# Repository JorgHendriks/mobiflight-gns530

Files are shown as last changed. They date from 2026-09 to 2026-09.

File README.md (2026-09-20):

# GNS 530 Flight-Simulator GPS

A DIY Garmin GNS 530-inspired panel for flight simulation, designed for use with [MobiFlight](https://www.mobiflight.com/). The project includes a Raspberry Pi Pico, custom PCB, a 5-inch LCD, a printed and laser-engraved enclosure, Mobiflight configuration.

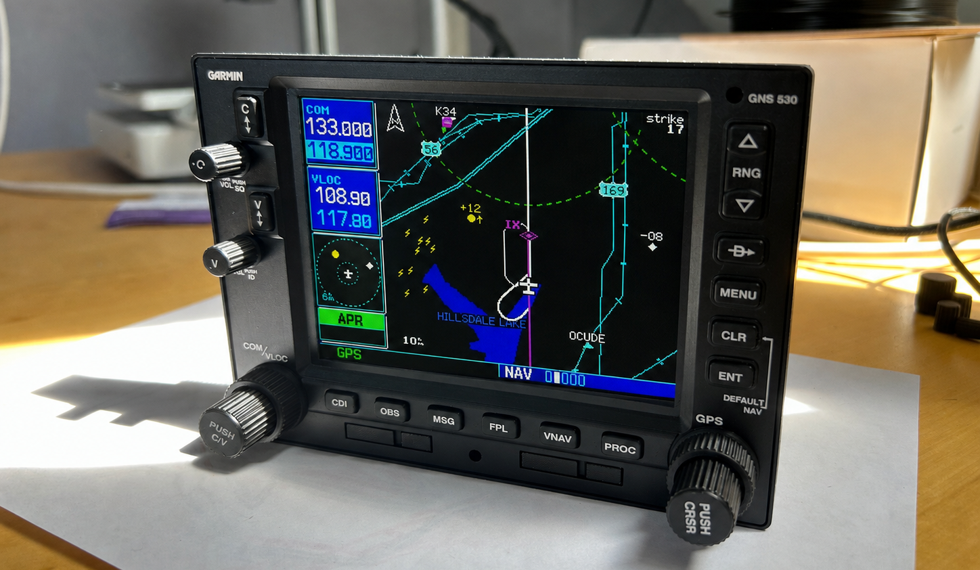
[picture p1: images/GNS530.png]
Completed GNS 530 flight-simulator panel


> [!IMPORTANT]
> This is an unofficial hobby project for flight simulation. It is not certified
> for aviation use and is not affiliated with or endorsed by Garmin.

## Features

- COM/VLOC and GPS dual-concentric encoders
- Illuminated GNS 530 controls
- 5-inch 640 x 480 display with HDMI, VGA, and composite-video input
- Adjustable panel illumination
- Editable KiCad and FreeCAD sources
- Printable parts, laser artwork, schematic, BOM, and PCB fabrication files

## Repository contents

| Folder | Contents |
|---|---|
| [`pcb`](pcb) | KiCad source, schematic, BOM, fabrication archive, display references, and assembly notes |
| [`mechanical`](mechanical) | FreeCAD source, printable parts, hardware, painting, and laser settings |
| [`mobiflight`](mobiflight) | Pico module configuration and Microsoft Flight Simulator project |

## What you need

- The components in the [PCB bill of materials](pcb/README.md#bill-of-materials)
- The printed parts and GNS530-specific [mounting hardware](mechanical/README.md#hardware)
- PCB800099 video controller and ZJ050NA-08C 5-inch LCD
- 12 V DC power supply rated above 1 A for the video controller
- Raspberry Pi Pico, MobiFlight

## Build documentation

1. Manufacture and assemble the board using the [PCB guide](pcb).
2. Print, paint, engrave, and assemble the enclosure using the
   [mechanical guide](mechanical).
3. Use the official MobiFlight documentation for
   [board configurations](https://docs.mobiflight.com/features/file-types/),
   [projects](https://docs.mobiflight.com/features/projects/), and
   [controller bindings](https://docs.mobiflight.com/features/controller-bindings/).

The supplied MobiFlight files are [`GNS530.mfmc`](mobiflight/GNS530.mfmc) and
[`GNS530.mfproj`](mobiflight/GNS530.mfproj).

## Licence

Original project material is licensed under
[CC BY-NC-SA 4.0](https://creativecommons.org/licenses/by-nc-sa/4.0/).
Third-party material and trademarks remain the property of their owners.

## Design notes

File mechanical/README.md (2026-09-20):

# Enclosure and controls

## Hardware

| Part | Quantity |
|---|---:|
| M2 x 8 mm screw | 5 |
| M2 x 4 mm screw | 4 |
| M2 x 9 mm, 3 mm body standoff | 5 |
| M2 x 4 mm, 3 mm body standoff | 4 |
| M2 x 11 mm, 3 mm body standoff | 4 |

## Printed parts

| File | Quantity | Material |
|---|---:|---|
| [`GNS530_case.3mf`](GNS530_case.3mf) | 1 | Matte-black PLA |
| [`GNS530_back_cover.3mf`](GNS530_back_cover.3mf) | 1 | Matte-black PLA |
| [`GNS530_faceplate.3mf`](GNS530_faceplate.3mf) | 1 | White PLA, painted matte black |
| [`GNS530_button.3mf`](GNS530_button.3mf) | 12 plus spares | White PLA, painted matte black |
| [`GNS530_button_rng.3mf`](GNS530_button_rng.3mf) | 1 plus a spare | White PLA, painted matte black |
| [`GNS530_knob_inner.3mf`](GNS530_knob_inner.3mf) | 2 | Black PLA |
| [`GNS530_knob_outer.3mf`](GNS530_knob_outer.3mf) | 2 | White PLA, painted matte black |
| [`GNS530_knob_volume.3mf`](GNS530_knob_volume.3mf) | 2 | White PLA, painted matte black |

The complete editable model is [`GNS530.FCStd`](GNS530.FCStd). Editable knob
sources are [`GNS530_encoder_dual.FCStd`](GNS530_encoder_dual.FCStd) and
[`GNS530_encoder_volume.FCStd`](GNS530_encoder_volume.FCStd).

## Printing

Print several spare knobs and buttons. They require little filament or paint, and achieving correct laser alignment may take more than one attempt.
Print inner knobs with their top surfaces facing down on a smooth PEI plate.

| Button setting | Value |
|---|---|
| Wall generator | Arachne |
| Initial-layer flow ratio | 1.06 |
| Bottom-surface pattern | Hilbert curve |
| Elephant-foot compensation | 0.08 mm |

Print the buttons and the faceplate with its visible face upward and enable ironing at 23% flow.

## Painting and laser engraving

Apply thin coats of matte-black paint to the white PLA parts. Let the paint cure fully before engraving.

The artwork is [`GNS530_laser.svg`](GNS530_laser.svg).

Reference settings for a Mecpow X3 Pro 10 W diode laser:

| Operation | Power | Speed |
|---|---:|---:|
| Faceplate and button raster | 15% | 2800 mm/min |
| Positioning outline | 50% | 2000 mm/min |

Run separate sessions for the faceplate, knobs, standard buttons, and range rocker.
Focus on the part surface, remove the part, engrave its positioning outline onto a sacrificial surface, then replace the part inside the outline and run the raster engraving.

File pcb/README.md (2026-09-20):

# PCB

## PCB manufacturing

The ready-to-order fabrication archive is
[`GNS530_v1_1_pcb_fab.zip`](GNS530_v1_1_pcb_fab.zip). Use a standard board
thickness of **1.6 mm**.

- [KiCad project](GNS530.kicad_pro)
- [Schematic PDF](GNS530_schematic.pdf)

The local symbol and footprint libraries are referenced through `${KIPRJMOD}`.

## Bill of materials

| Designators | Qty | Component | Specification |
|---|---:|---|---|
| RE_GPS1, RE_COM_VLOC1 | 2 | Dual-concentric encoder | PEC11D-4120F-S0015 |
| Q2 | 1 | P-channel MOSFET | AO3401A, SOT-23 |
| C1 | 1 | Capacitor | 0.1 uF, 1206 |
| R1-R23, R32-R36 | 28 | Resistor | 220 ohm, 1206 |
| R24-R31, R39, R40 | 10 | Resistor | 10 kohm, 1206 |
| Q1 | 1 | NPN transistor | BC847, SOT-23 |
| SW_CDI1, SW_CLR1, SW_COM1, SW_DCT1, SW_ENT1, SW_FPL1, SW_MENU1, SW_MSG1, SW_OBS1, SW_PROC1, SW_RNG_D1, SW_RNG_UP1, SW_V1, SW_VNAV1 | 14 | Illuminated tactile switch | 6 x 6 x 7.2 mm, six pins |
| D1-D14 | 14 | LED | 3 mm clear through-hole |
| U1 | 1 | Shift register | 74HC165, SOIC-16 |
| RE_VOL_COM1, RE_VOL_V1 | 2 | Rotary encoder with switch | PEC11L-4220F-S0015 |
| EXT_LED1 | 1 | Two-pin header | 2.54 mm pitch |
| A1 | 1 | Microcontroller | Raspberry Pi Pico |
| - | 2 | Male pin header | 20 pins, 2.54 mm pitch |
| - | 2 | Female socket header | 20 pins, 2.54 mm pitch |

## Illuminated switches

Use 6 x 6 x 7.2 mm, six-pin illuminated tactile switches. Four pins form the
duplicated switch contacts; the remaining two connect the LED.

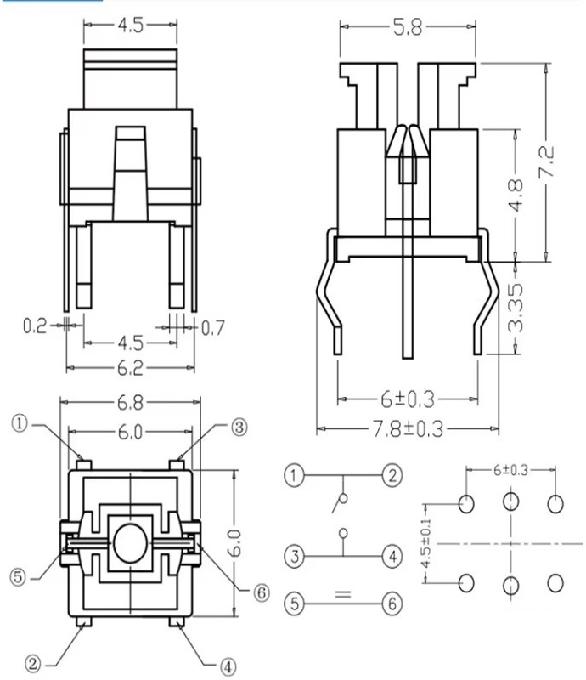
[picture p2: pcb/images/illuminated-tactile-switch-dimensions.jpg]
Illuminated tactile switch dimensions


The small square PCB pad is ground and connects to the negative LED terminal.

## Display

The enclosure is designed for a **PCB800099** HDMI/VGA/AV controller and
**ZJ050NA-08C** 5-inch 640 x 480 LCD.

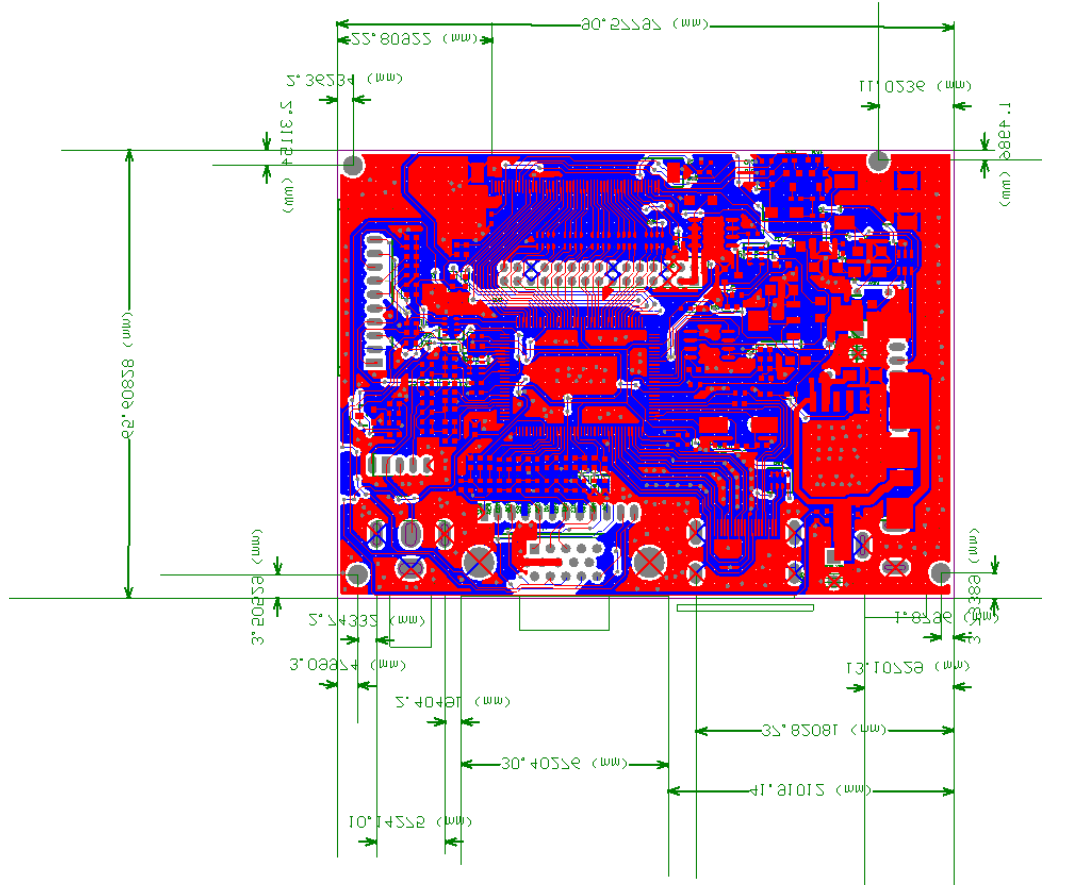
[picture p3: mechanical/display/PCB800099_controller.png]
PCB800099 controller


| Part | Specification |
|---|---|
| PCB800099 controller | 100 x 55 x 10 mm; 12 V DC, more than 1 A |
| ZJ050NA-08C LCD | 117.65 x 88.43 x 5.9 mm; 50-pin parallel RGB |

- [Controller dimensions](../mechanical/display/PCB800099_dimensions.png)
- [Controller datasheet](../mechanical/display/PCB800099_datasheet.pdf)
- [LCD datasheet](../mechanical/display/ZJ050NA-08C_datasheet.pdf)
- [Controller product image](../mechanical/display/PCB800099_product.jpg)

The display controller uses its own 12 V supply. Do not connect 12 V to the Pico or the LCD panel input.

If your controller board includes VGA and composite-video connectors, desolder
them before assembly. Alternatively, modify the back cover to provide adequate
clearance for the connectors.

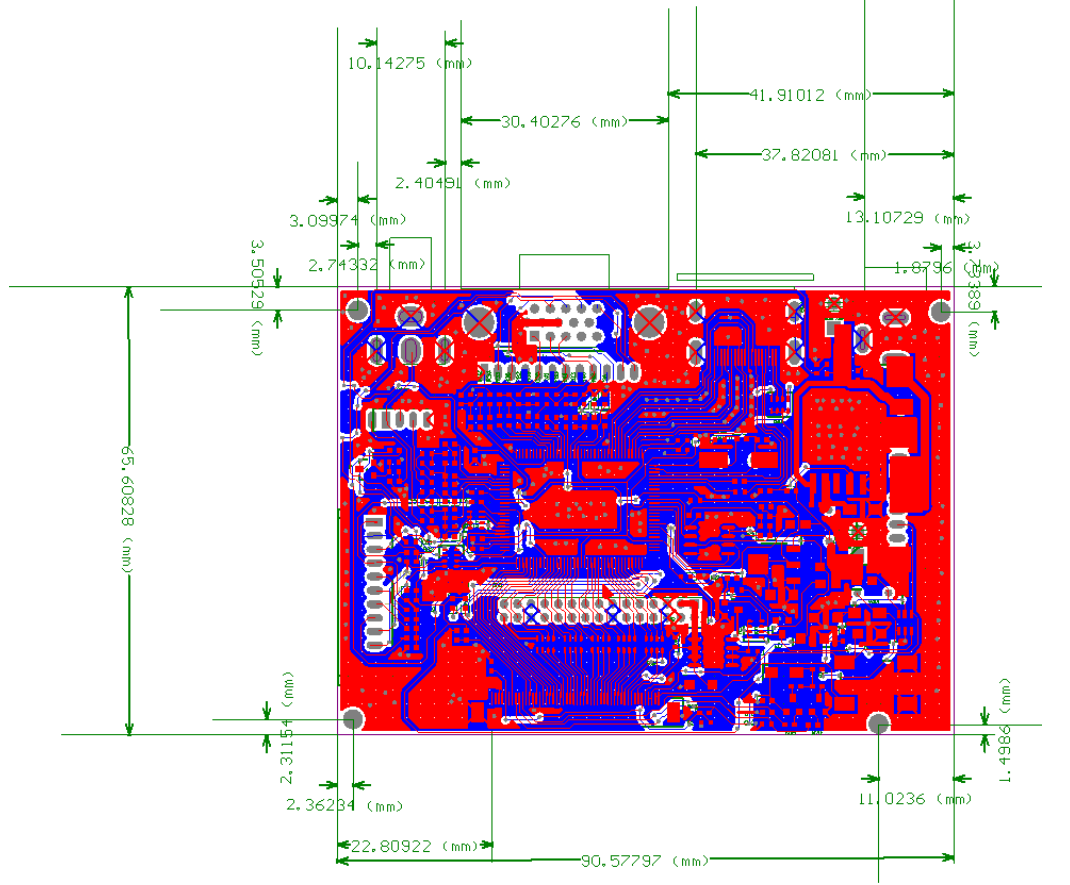
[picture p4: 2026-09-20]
mechanical/display/PCB800099_dimensions.png

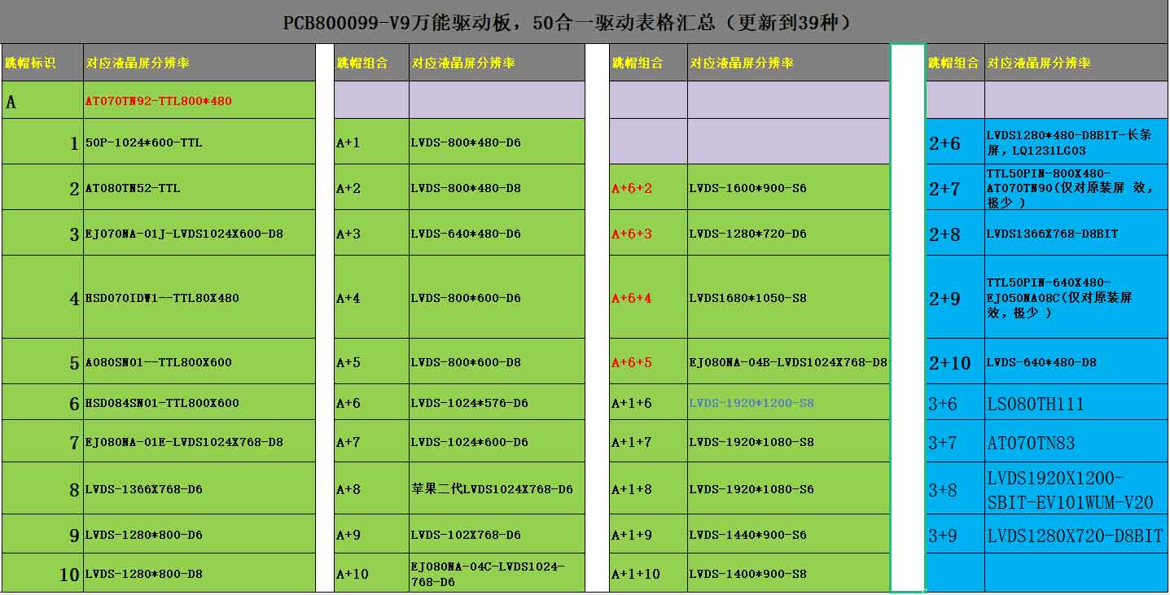
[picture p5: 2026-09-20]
mechanical/display/PCB800099_product.jpg

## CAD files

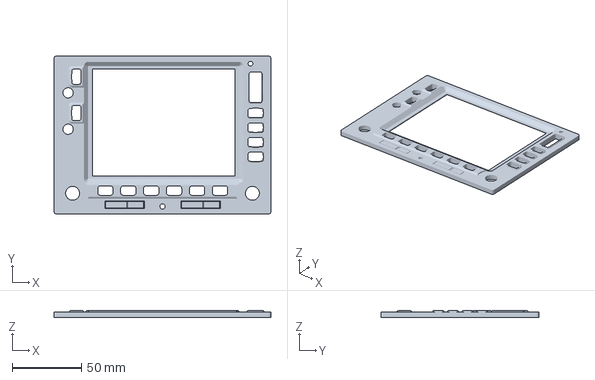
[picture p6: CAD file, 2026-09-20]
mechanical/GNS530_faceplate.3mf
156.3 x 113.9 x 5.00 mm

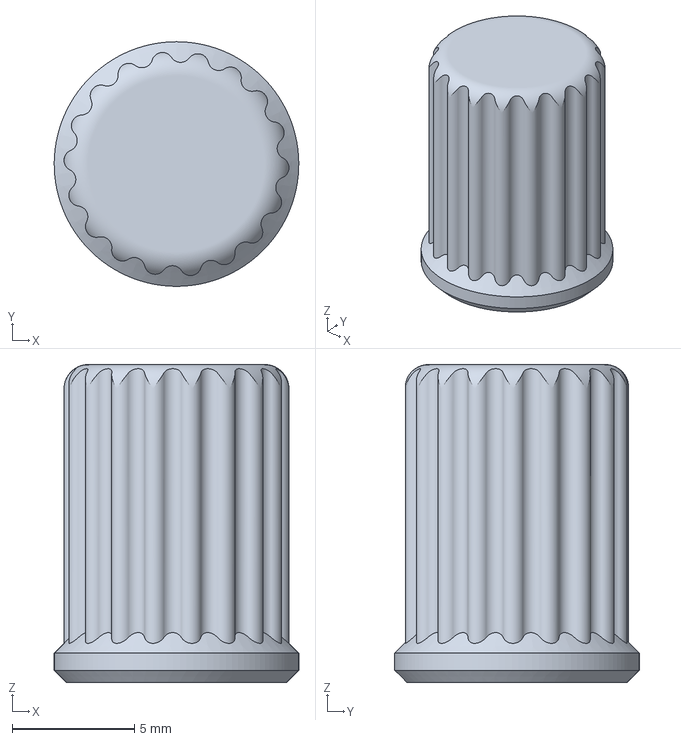
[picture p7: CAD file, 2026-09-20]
mechanical/GNS530_knob_volume.3mf
10.00 x 10.00 x 13.0 mm

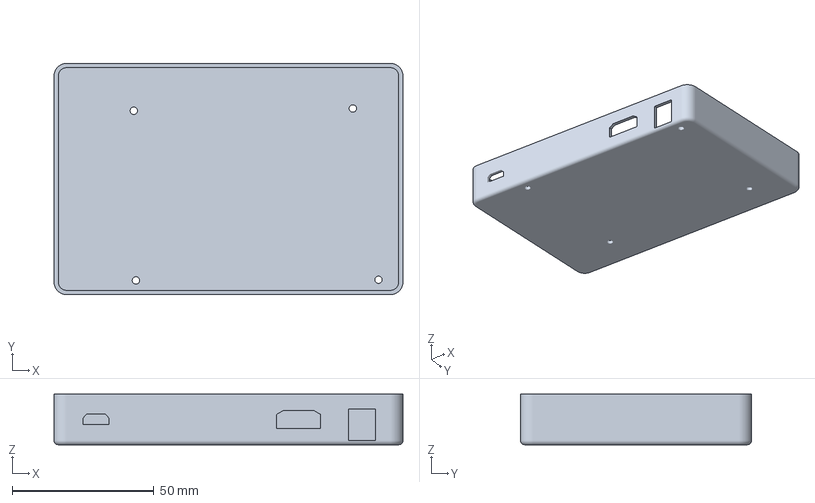
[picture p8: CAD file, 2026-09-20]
mechanical/GNS530_back_cover.3mf
123.0 x 81.5 x 17.8 mm

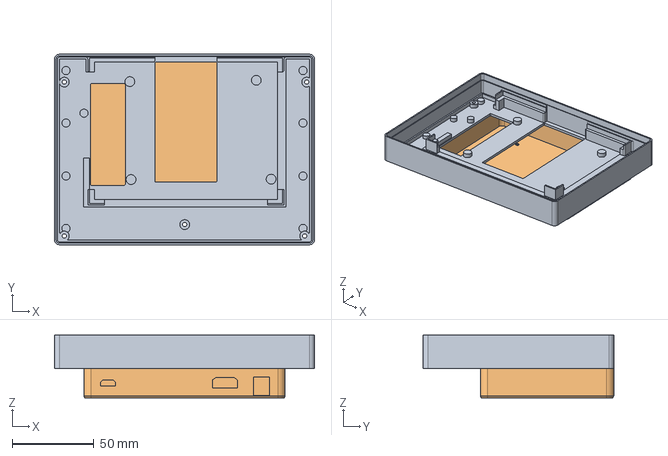
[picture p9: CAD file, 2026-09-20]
mechanical/GNS530.FCStd
158.8 x 116.3 x 38.2 mm
Case
hdmi_cover

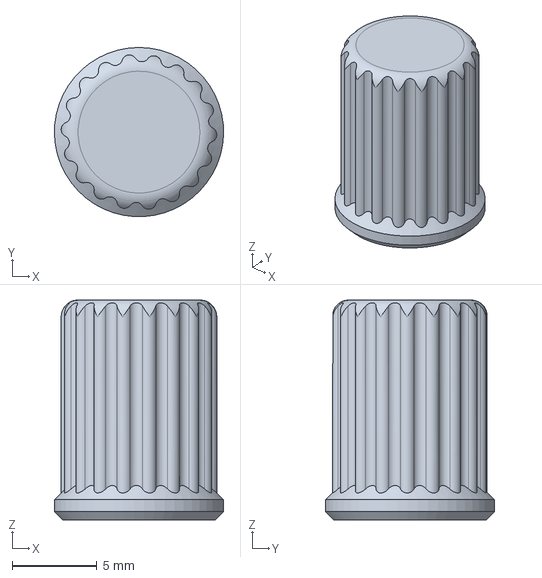
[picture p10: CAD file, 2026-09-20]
mechanical/GNS530_encoder_volume.FCStd
10.00 x 9.99 x 13.0 mm

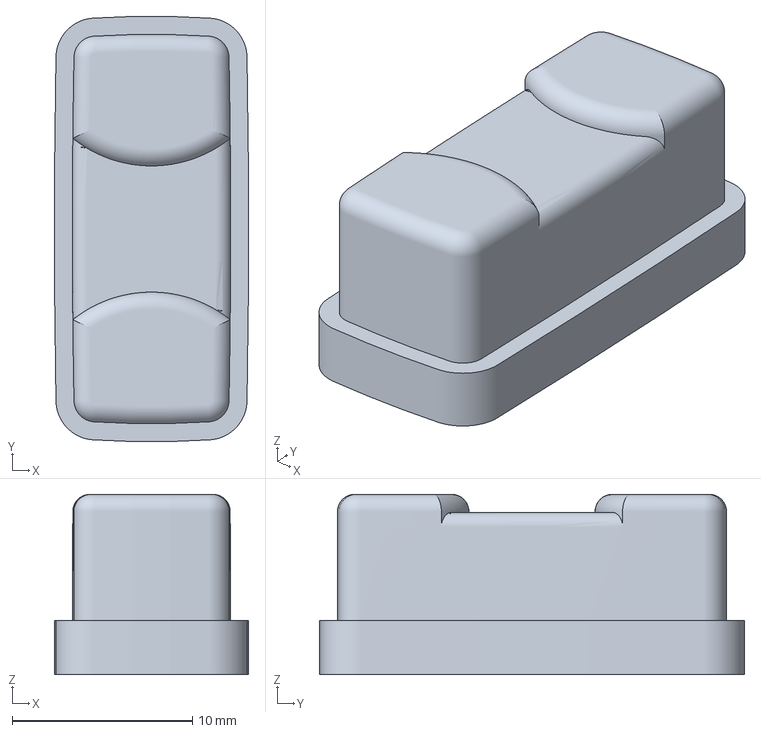
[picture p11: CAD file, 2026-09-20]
mechanical/GNS530_button_rng.3mf
10.8 x 23.6 x 10.0 mm

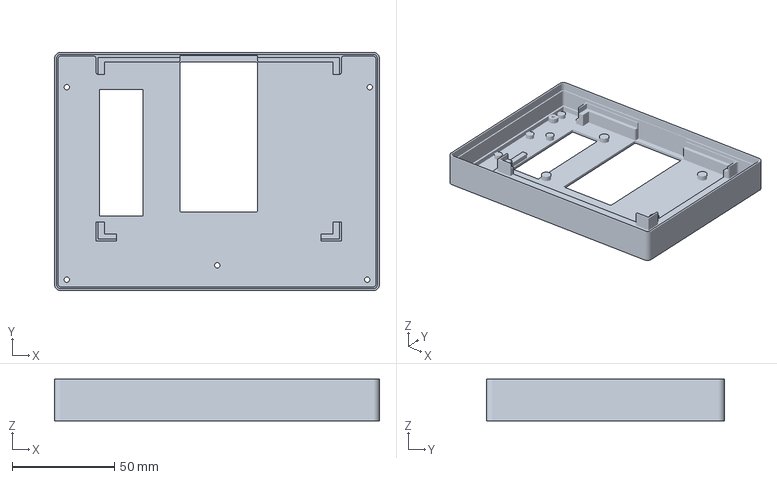
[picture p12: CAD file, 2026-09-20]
mechanical/GNS530_case.3mf
158.8 x 116.3 x 20.4 mm

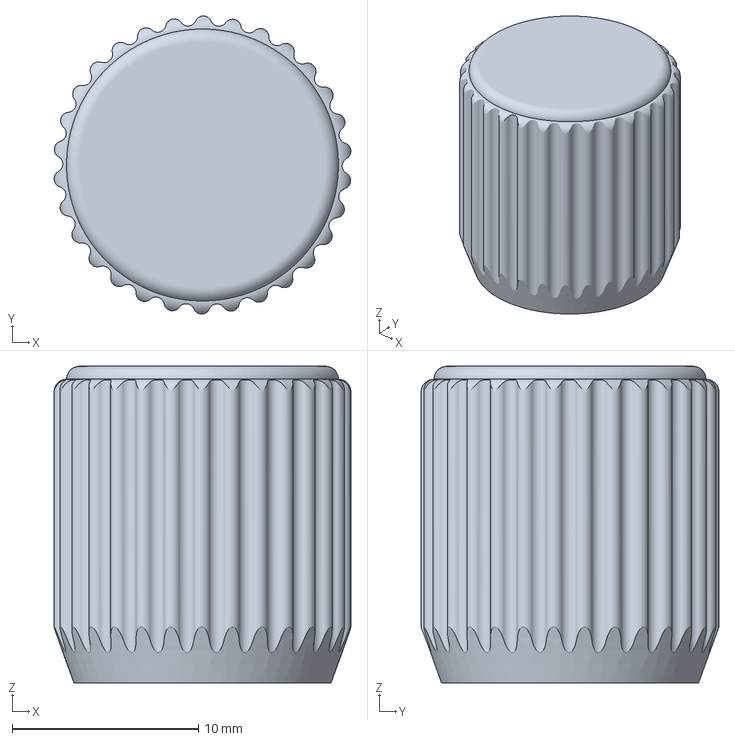
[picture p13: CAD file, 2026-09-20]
mechanical/GNS530_knob_inner.3mf
15.9 x 16.0 x 17.0 mm

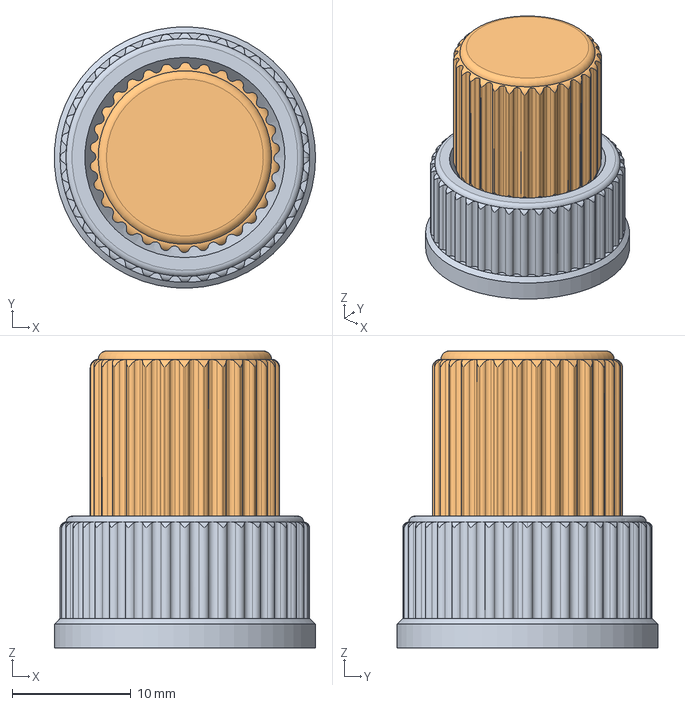
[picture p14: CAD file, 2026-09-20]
mechanical/GNS530_encoder_dual.FCStd
22.0 x 22.0 x 25.0 mm
outer
inner

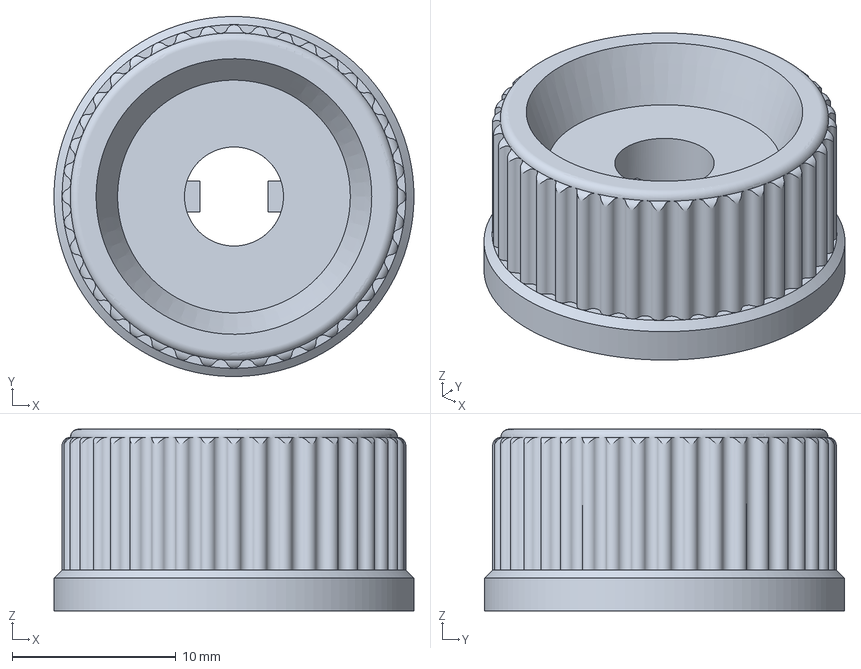
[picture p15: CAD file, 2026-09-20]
mechanical/GNS530_knob_outer.3mf
22.0 x 22.0 x 11.1 mm

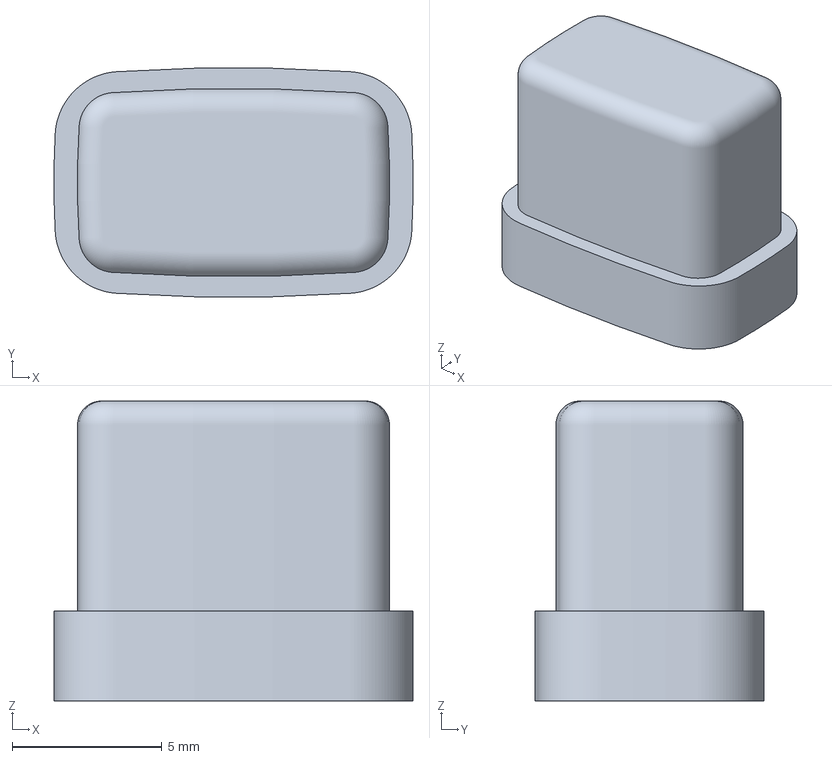
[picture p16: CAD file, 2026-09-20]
mechanical/GNS530_button.3mf
12.0 x 7.62 x 10.0 mm

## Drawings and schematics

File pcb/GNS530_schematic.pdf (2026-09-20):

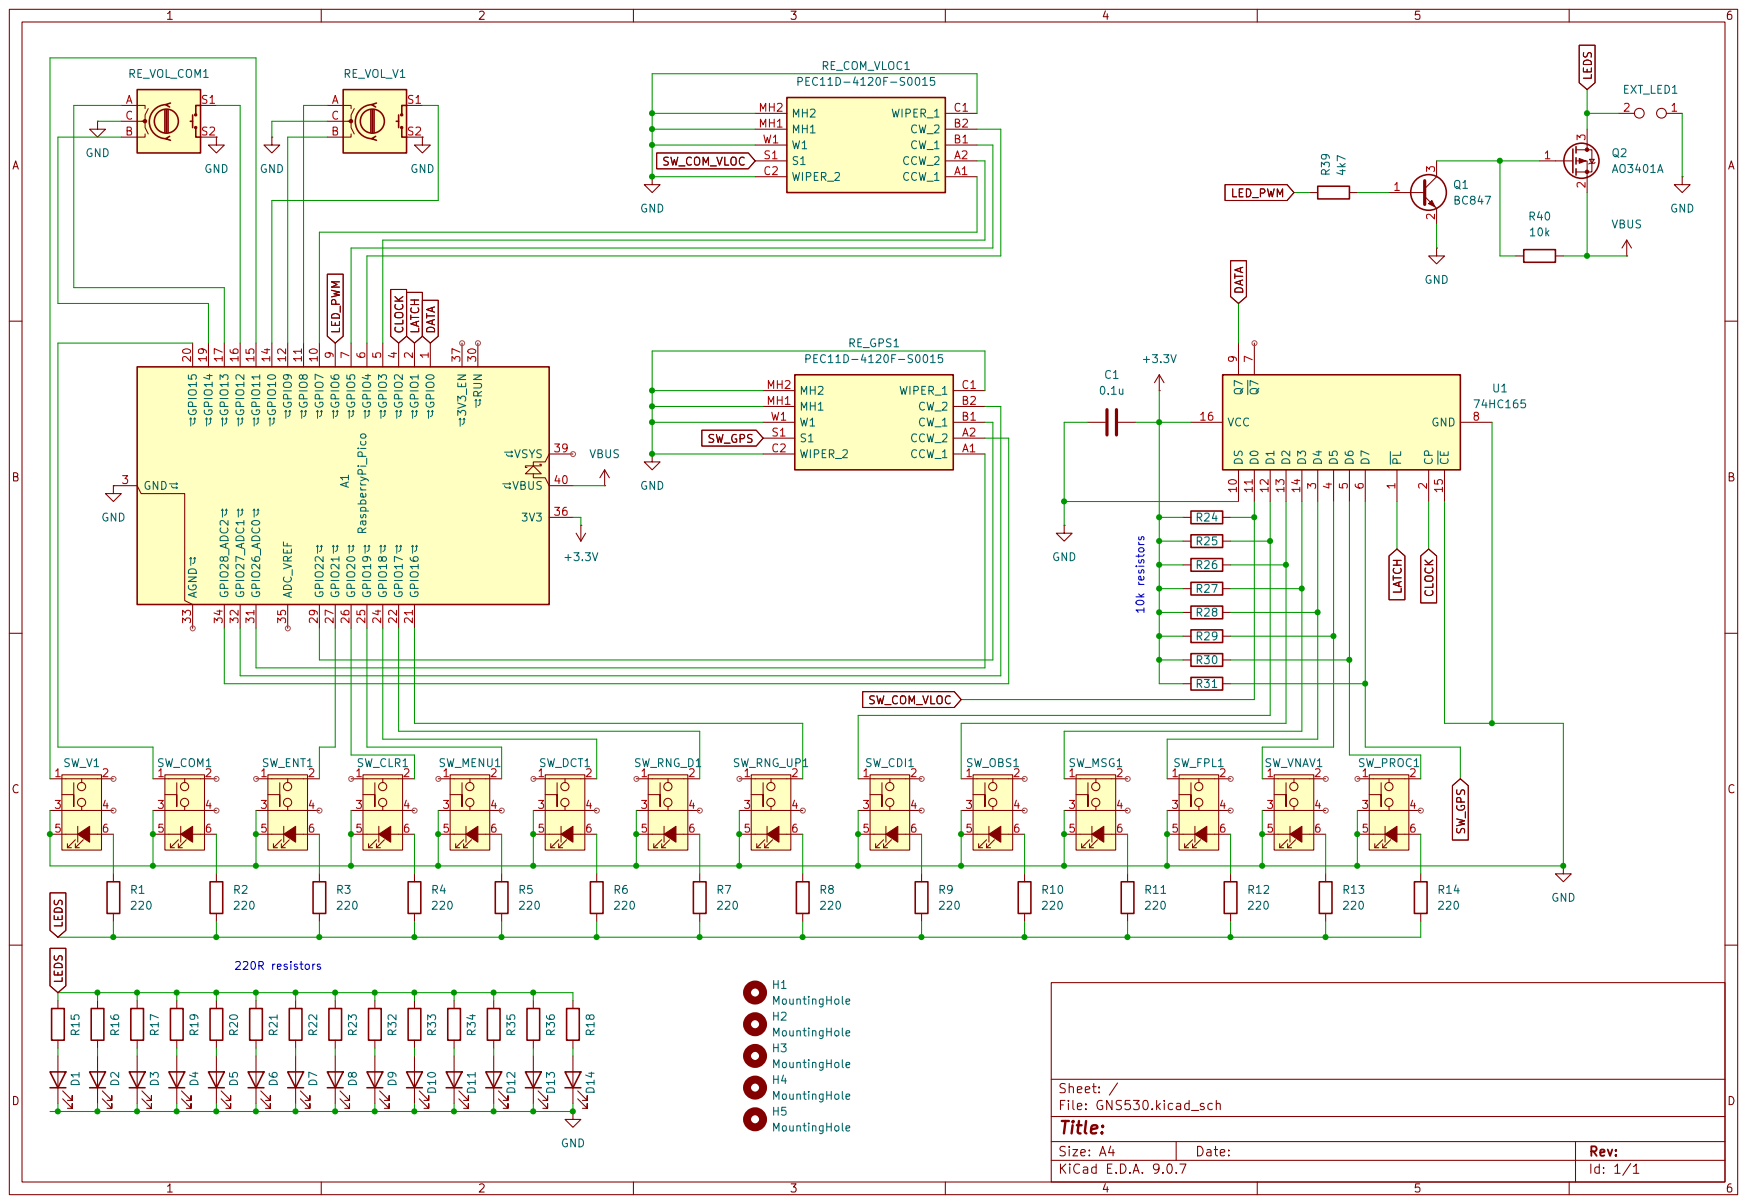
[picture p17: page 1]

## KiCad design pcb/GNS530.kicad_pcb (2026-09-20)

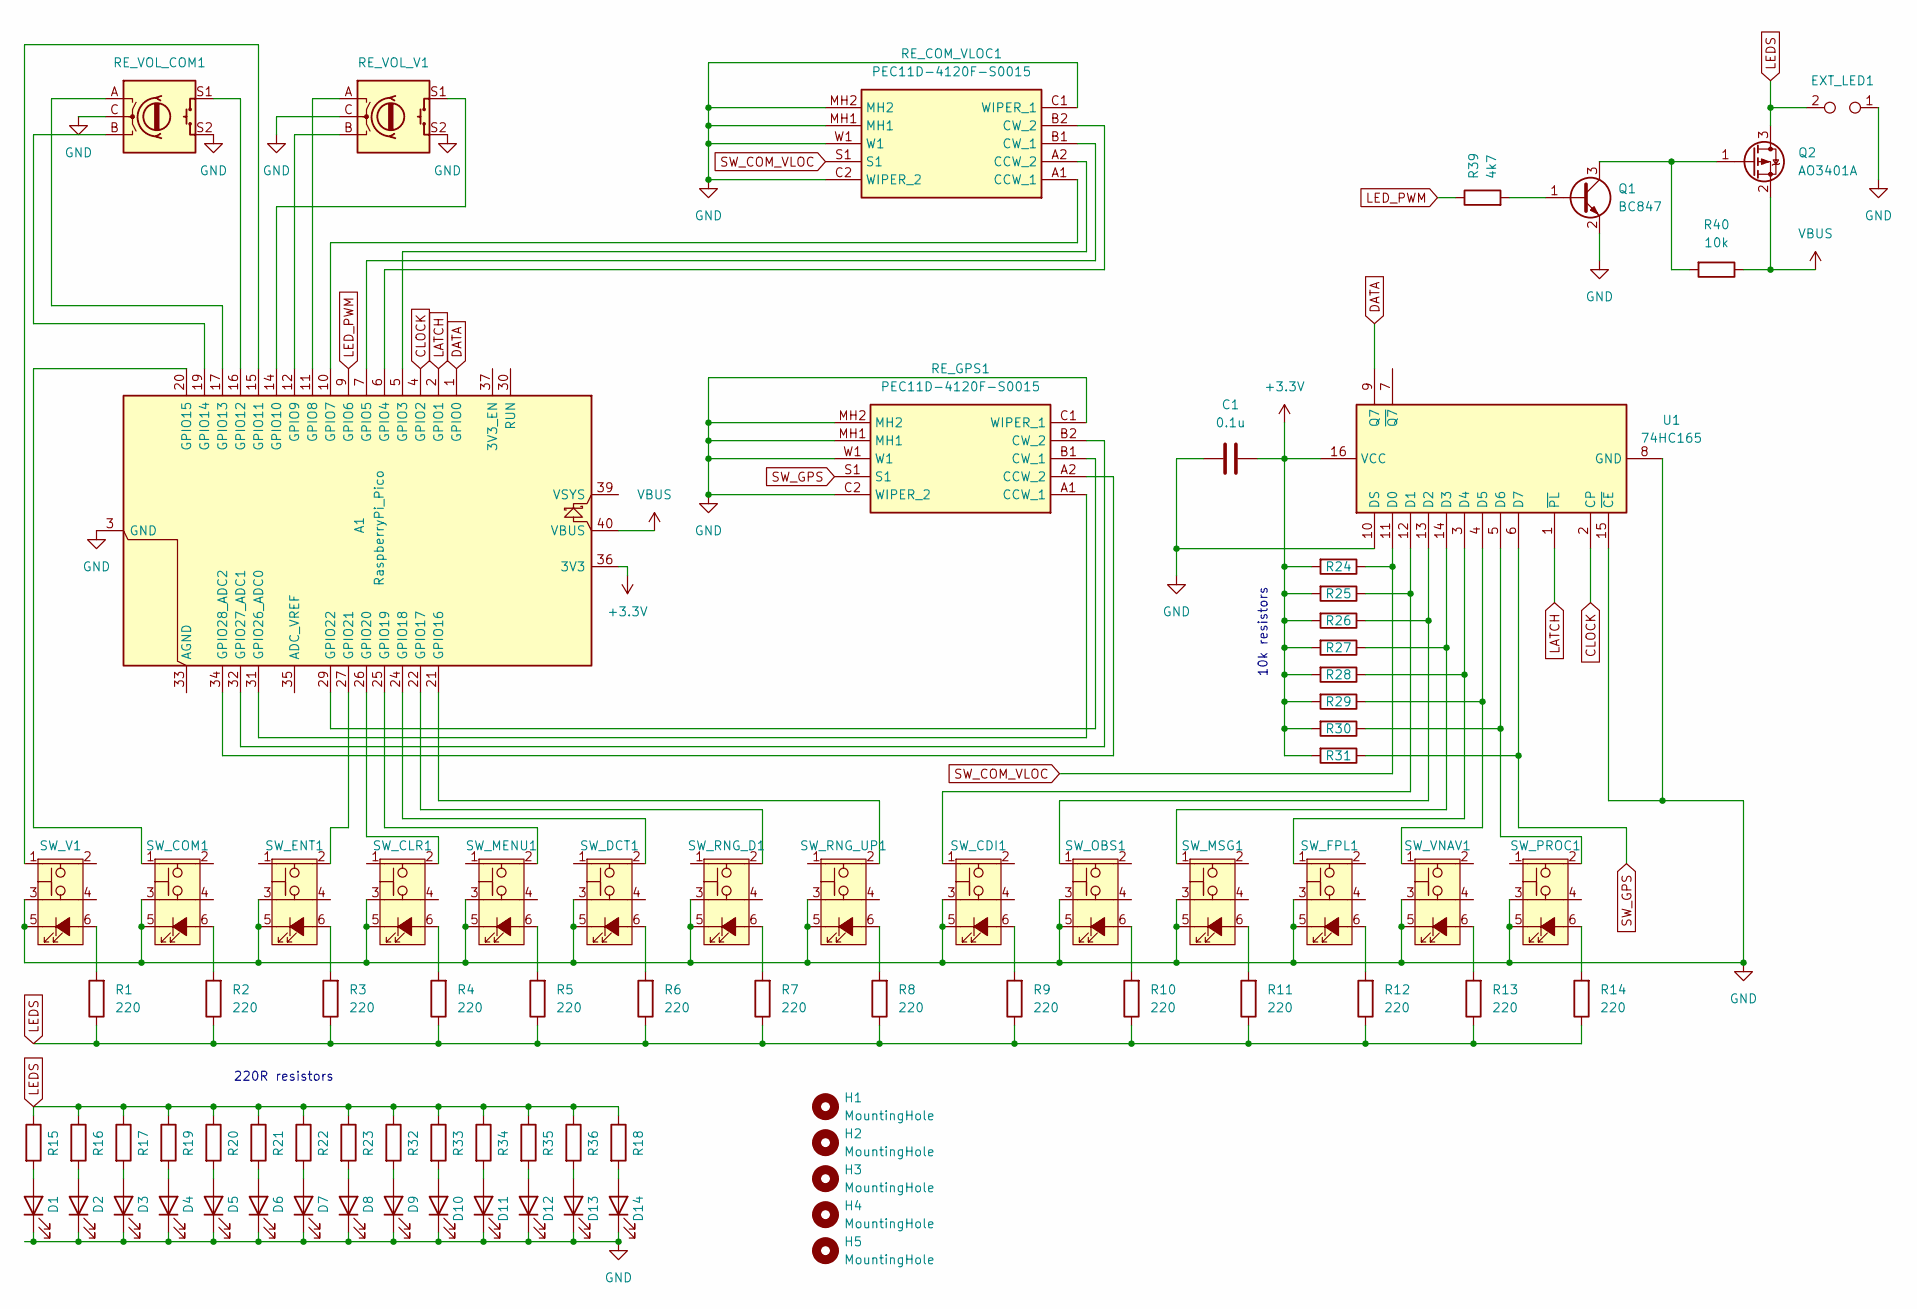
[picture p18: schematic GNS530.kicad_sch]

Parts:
A1: RaspberryPi_Pico; RaspberryPi_Pico_Common_Unspecified
C1: 0.1u; R_1206_3216Metric
D1, D2, D3, D4, D5, D6, D7, D8, D9, D10, D11, D12, D13, D14: LED; LED_D3.0mm_Clear
EXT_LED1: TestPoint_2Pole; PinHeader_2x01_P2.54mm_Vertical
H1, H2, H3, H4, H5: MountingHole; MountingHole_2.2mm_M2
Q1: BC847; SOT-23
Q2: AO3401A; SOT-23
R1, R2, R3, R4, R5, R6, R7, R8, R9, R10, R11, R12, R13, R14, R15, R16, R17, R18, R19, R20, R21, R22, R23, R32, R33, R34, R35, R36: 220; R_1206_3216Metric
R24, R25, R26, R27, R28, R29, R30, R31, R40: 10k; R_1206_3216Metric
R39: 4k7; R_1206_3216Metric
RE_COM_VLOC1: PEC11D-4120F-S0015; PEC11D4120FS0015; Mouser Part Number 652-PEC11D4120FS0015
RE_GPS1: PEC11D-4120F-S0015; PEC11D4120FS0015; Mouser Part Number 652-PEC11D4120FS0015
RE_VOL_COM1: RotaryEncoder_Switch; RotaryEncoder_Alps_EC11E-Switch_Vertical_H20mm
RE_VOL_V1: RotaryEncoder_Switch; RotaryEncoder_Alps_EC11E-Switch_Vertical_H20mm
SW_CDI1: SW_Push_LED_6p; SW_PUSH_LED_6mm_H7.2mm
SW_CLR1: SW_Push_LED_6p; SW_PUSH_LED_6mm_H7.2mm
SW_COM1: SW_Push_LED_6p; SW_PUSH_LED_6mm_H7.2mm
SW_DCT1: SW_Push_LED_6p; SW_PUSH_LED_6mm_H7.2mm
SW_ENT1: SW_Push_LED_6p; SW_PUSH_LED_6mm_H7.2mm
SW_FPL1: SW_Push_LED_6p; SW_PUSH_LED_6mm_H7.2mm
SW_MENU1: SW_Push_LED_6p; SW_PUSH_LED_6mm_H7.2mm
SW_MSG1: SW_Push_LED_6p; SW_PUSH_LED_6mm_H7.2mm
SW_OBS1: SW_Push_LED_6p; SW_PUSH_LED_6mm_H7.2mm
SW_PROC1: SW_Push_LED_6p; SW_PUSH_LED_6mm_H7.2mm
SW_RNG_D1: SW_Push_LED_6p; SW_PUSH_LED_6mm_H7.2mm
SW_RNG_UP1: SW_Push_LED_6p; SW_PUSH_LED_6mm_H7.2mm
SW_V1: SW_Push_LED_6p; SW_PUSH_LED_6mm_H7.2mm
SW_VNAV1: SW_Push_LED_6p; SW_PUSH_LED_6mm_H7.2mm
U1: 74HC165; JEITA_SOIC-16_3.9x9.9mm_P1.27mm

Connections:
+3.3V: A1.36 (3V3), C1.2, R24.2, R25.2, R26.2, R27.2, R28.2, R29.2, R30.2, R31.2, U1.16 (VCC)
CLOCK: A1.4 (GPIO2), U1.2 (CP)
DATA: A1.1 (GPIO0), U1.9 (Q7)
GND: A1.3 (GND), A1.8 (GND), A1.13 (GND), A1.18 (GND), A1.23 (GND), A1.28 (GND), A1.38 (GND), C1.1, D1.1 (K), D2.1 (K), D3.1 (K), D4.1 (K), D5.1 (K), D6.1 (K), D7.1 (K), D8.1 (K), D9.1 (K), D10.1 (K), D11.1 (K), D12.1 (K), D13.1 (K), D14.1 (K), EXT_LED1.1, Q1.2 (E), RE_COM_VLOC1.C1 (WIPER_1), RE_COM_VLOC1.C2 (WIPER_2), RE_COM_VLOC1.MH1, RE_COM_VLOC1.MH2, RE_COM_VLOC1.W1, RE_GPS1.C1 (WIPER_1), RE_GPS1.C2 (WIPER_2), RE_GPS1.MH1, RE_GPS1.MH2, RE_GPS1.W1, RE_VOL_COM1.C, RE_VOL_COM1.S2, RE_VOL_V1.C, RE_VOL_V1.S2, SW_CDI1.3, SW_CDI1.5 (K), SW_CLR1.3, SW_CLR1.5 (K), SW_COM1.3, SW_COM1.5 (K), SW_DCT1.3, SW_DCT1.5 (K), SW_ENT1.3, SW_ENT1.5 (K), SW_FPL1.3, SW_FPL1.5 (K), SW_MENU1.3, SW_MENU1.5 (K), SW_MSG1.3, SW_MSG1.5 (K), SW_OBS1.3, SW_OBS1.5 (K), SW_PROC1.3, SW_PROC1.5 (K), SW_RNG_D1.3, SW_RNG_D1.5 (K), SW_RNG_UP1.3, SW_RNG_UP1.5 (K), SW_V1.3, SW_V1.5 (K), SW_VNAV1.3, SW_VNAV1.5 (K), U1.8 (GND), U1.10 (DS), U1.15 (~CE)
LATCH: A1.2 (GPIO1), U1.1 (~PL)
LEDS: EXT_LED1.2, Q2.3 (D), R1.1, R2.1, R3.1, R4.1, R5.1, R6.1, R7.1, R8.1, R9.1, R10.1, R11.1, R12.1, R13.1, R14.1, R15.1, R16.1, R17.1, R18.1, R19.1, R20.1, R21.1, R22.1, R23.1, R32.1, R33.1, R34.1, R35.1, R36.1
LED_PWM: A1.9 (GPIO6), R39.1
unnamed: A1.5 (GPIO3), RE_COM_VLOC1.A2 (CCW_2)
unnamed: A1.6 (GPIO4), RE_COM_VLOC1.B2 (CW_2)
unnamed: A1.7 (GPIO5), RE_COM_VLOC1.B1 (CW_1)
unnamed: A1.10 (GPIO7), RE_COM_VLOC1.A1 (CCW_1)
unnamed: A1.11 (GPIO8), RE_VOL_V1.A
unnamed: A1.12 (GPIO9), RE_VOL_V1.B
unnamed: A1.14 (GPIO10), RE_VOL_V1.S1
unnamed: A1.15 (GPIO11), SW_V1.1
unnamed: A1.16 (GPIO12), RE_VOL_COM1.S1
unnamed: A1.17 (GPIO13), RE_VOL_COM1.A
unnamed: A1.19 (GPIO14), RE_VOL_COM1.B
unnamed: A1.20 (GPIO15), SW_COM1.1
unnamed: A1.21 (GPIO16), SW_RNG_UP1.2
unnamed: A1.22 (GPIO17), SW_RNG_D1.2
unnamed: A1.24 (GPIO18), SW_DCT1.2
unnamed: A1.25 (GPIO19), SW_MENU1.2
unnamed: A1.26 (GPIO20), SW_CLR1.2
unnamed: A1.27 (GPIO21), SW_ENT1.2
unnamed: A1.29 (GPIO22), RE_GPS1.B1 (CW_1)
unnamed: A1.31 (GPIO26_ADC0), RE_GPS1.A1 (CCW_1)
unnamed: A1.32 (GPIO27_ADC1), RE_GPS1.B2 (CW_2)
unnamed: A1.34 (GPIO28_ADC2), RE_GPS1.A2 (CCW_2)
unnamed: D1.2 (A), R15.2
unnamed: D2.2 (A), R16.2
unnamed: D3.2 (A), R17.2
unnamed: D4.2 (A), R19.2
unnamed: D5.2 (A), R20.2
unnamed: D6.2 (A), R21.2
unnamed: D7.2 (A), R22.2
unnamed: D8.2 (A), R23.2
unnamed: D9.2 (A), R32.2
unnamed: D10.2 (A), R33.2
unnamed: D11.2 (A), R34.2
unnamed: D12.2 (A), R35.2
unnamed: D13.2 (A), R36.2
unnamed: D14.2 (A), R18.2
unnamed: Q1.1 (B), R39.2
unnamed: Q1.3 (C), Q2.1 (G), R40.2
unnamed: R1.2, SW_V1.6
unnamed: R2.2, SW_COM1.6
unnamed: R3.2, SW_ENT1.6
unnamed: R4.2, SW_CLR1.6
unnamed: R5.2, SW_MENU1.6
unnamed: R6.2, SW_DCT1.6
unnamed: R7.2, SW_RNG_D1.6
unnamed: R8.2, SW_RNG_UP1.6
unnamed: R9.2, SW_CDI1.6
unnamed: R10.2, SW_OBS1.6
unnamed: R11.2, SW_MSG1.6
unnamed: R12.2, SW_FPL1.6
unnamed: R13.2, SW_VNAV1.6
unnamed: R14.2, SW_PROC1.6
unnamed: R25.1, SW_CDI1.1, U1.12 (D1)
unnamed: R26.1, SW_OBS1.1, U1.13 (D2)
unnamed: R27.1, SW_MSG1.1, U1.14 (D3)
unnamed: R28.1, SW_FPL1.1, U1.3 (D4)
unnamed: R29.1, SW_VNAV1.1, U1.4 (D5)
unnamed: R30.1, SW_PROC1.2, U1.5 (D6)
SW_COM_VLOC: R24.1, RE_COM_VLOC1.S1, U1.11 (D0)
SW_GPS: R31.1, RE_GPS1.S1, U1.6 (D7)
VBUS: A1.40 (VBUS), Q2.2 (S), R40.1

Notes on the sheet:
10k resistors
220R resistors

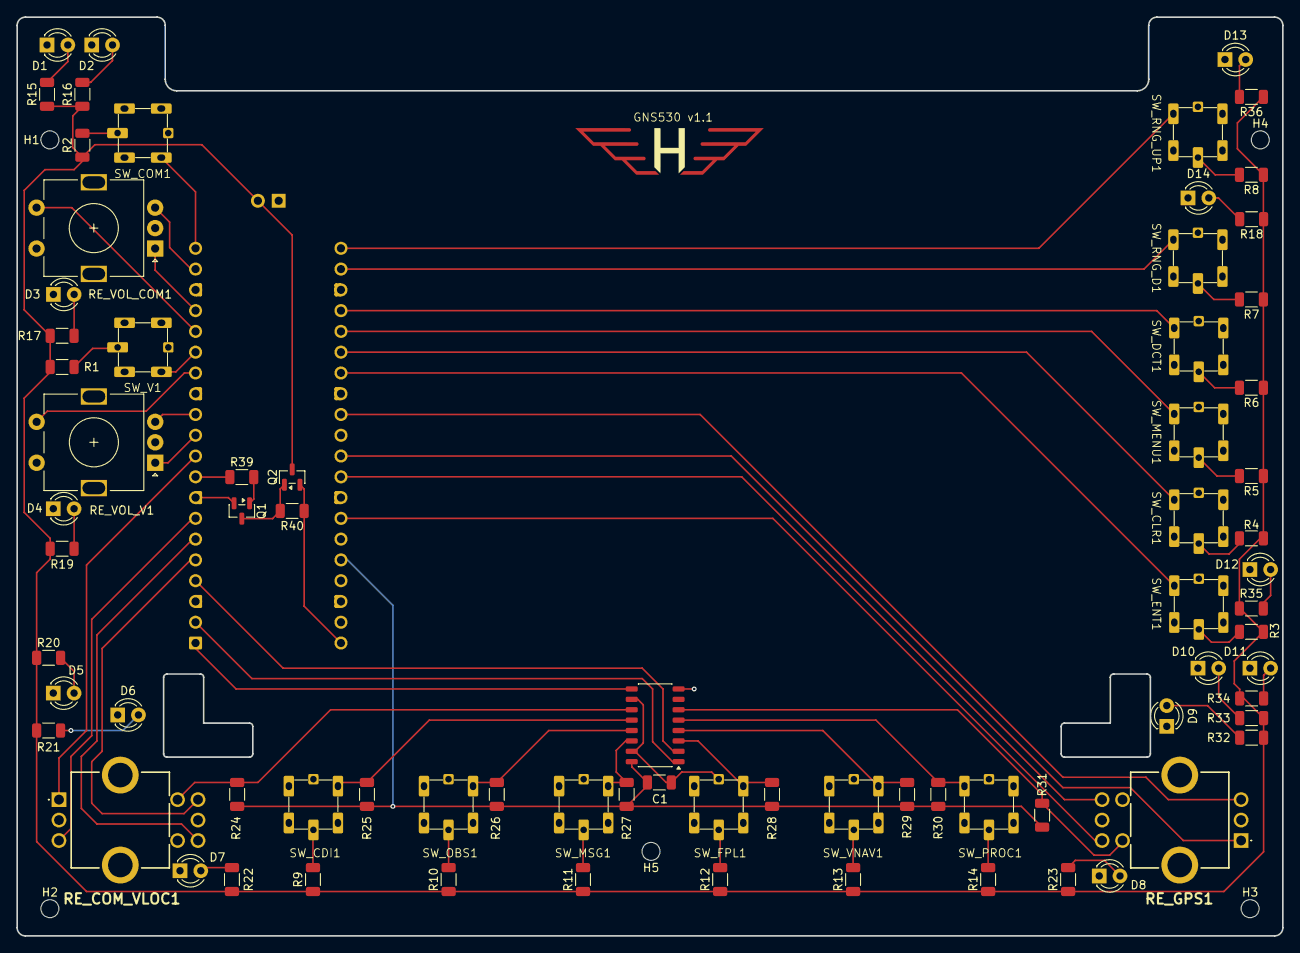
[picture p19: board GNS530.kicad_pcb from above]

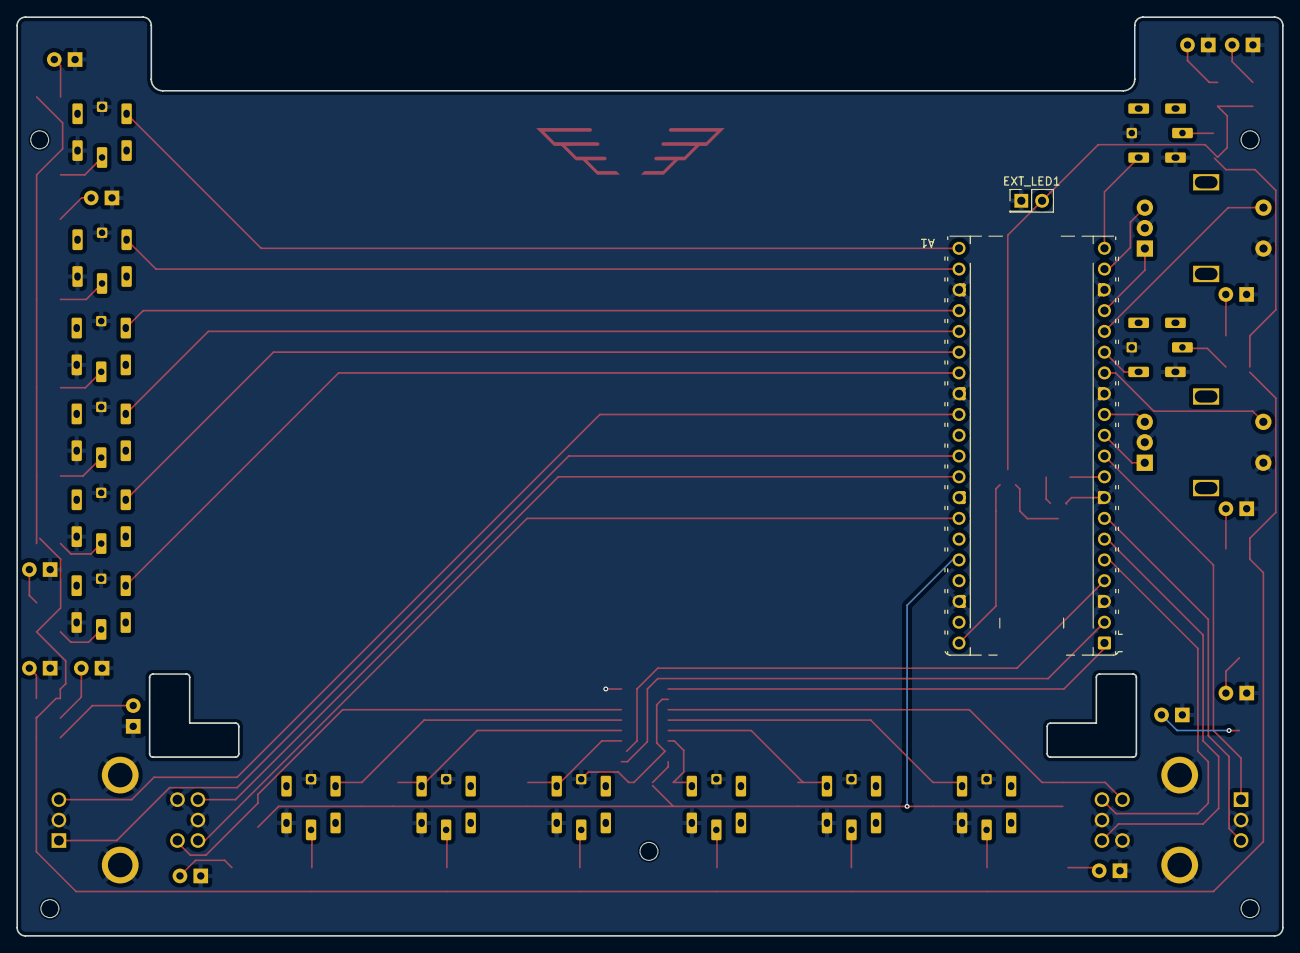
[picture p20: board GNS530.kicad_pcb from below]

Board: 2 copper layers, 154.8 x 112.3 mm, 81 parts (2 on the bottom side), 68 nets.
